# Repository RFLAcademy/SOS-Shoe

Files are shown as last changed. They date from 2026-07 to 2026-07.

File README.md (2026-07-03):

Smart Women Safety Insole - Companion App 🥿🚨

This is the official Android companion application for the Smart Women Safety Insole capstone project.

The system consists of a custom hardware insole (built with an ESP32-C3, SIM800C GPRS/GSM module, GPS, and an FSR sensor) and this Kotlin-based Android application. The app connects to a Traccar open-source backend to provide real-time location monitoring and emergency alert management.

🌟 Key Features

Live GPS Tracking: Integrates with the Google Maps SDK and Traccar API to display the real-time location of the shoe.

Route History: Automatically fetches and draws a polyline of the user's route history for the last 2 hours.

Instant SOS Alerts: If the user triggers the FSR sensor with a specific 3-taps, pause, 2-taps pattern, the app receives an immediate SOS flag and triggers a visual and auditory alarm.

Dynamic Hardware Configuration: Users can update the shoe's emergency contacts directly from the app. The app uses Android's native SmsManager to send hidden configuration commands (e.g., SET_EMERGENCY:9999999999) to the shoe, which saves the new numbers to its non-volatile flash memory.

Live Telemetry: Displays real-time speed (in knots) and UTC timestamps of the wearer's movements.

🛠️ Tech Stack

Language: Kotlin

Architecture: Android Views / XML Layouts

Maps: Google Maps API (play-services-maps)

Networking: Retrofit2 & OkHttp (for Traccar REST API communication)

Hardware Interfacing: SMS-based command transmission

🚀 How It Works

The Hardware: An ESP32 reads an FSR sensor. Upon detecting the SOS pattern, it sends an SMS to emergency contacts and pushes an &alarm=sos flag to the Traccar server via GPRS.

The Server: Traccar logs the GPS coordinates and the SOS flag.

The App: This Android app constantly polls the Traccar API using Retrofit. It updates the Google Map UI with the latest coordinates and triggers an alarm screen if the SOS flag is detected.

🔒 Setup Note

To run this project locally, you must provide your own MAPS_API_KEY in the local.properties file and set up a Traccar server instance.

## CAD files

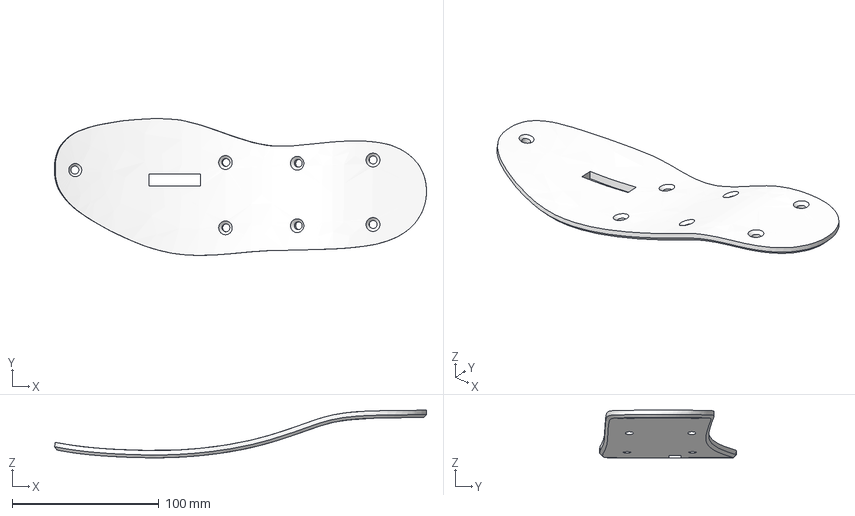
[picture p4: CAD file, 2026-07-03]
Mirrored files SOS shoes/mirrored upper shoe.step
253.7 x 93.3 x 32.5 mm

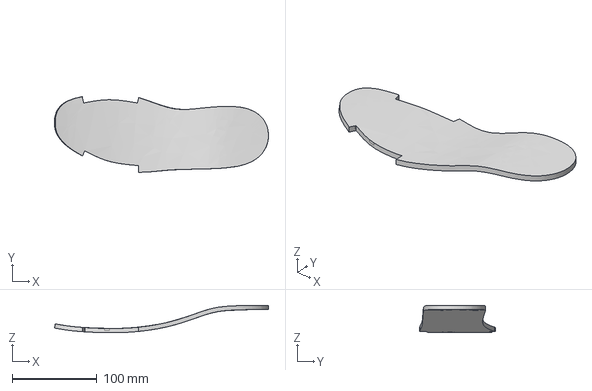
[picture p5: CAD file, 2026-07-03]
Mirrored files SOS shoes/mirrored TPU sole.step
253.1 x 89.6 x 32.5 mm

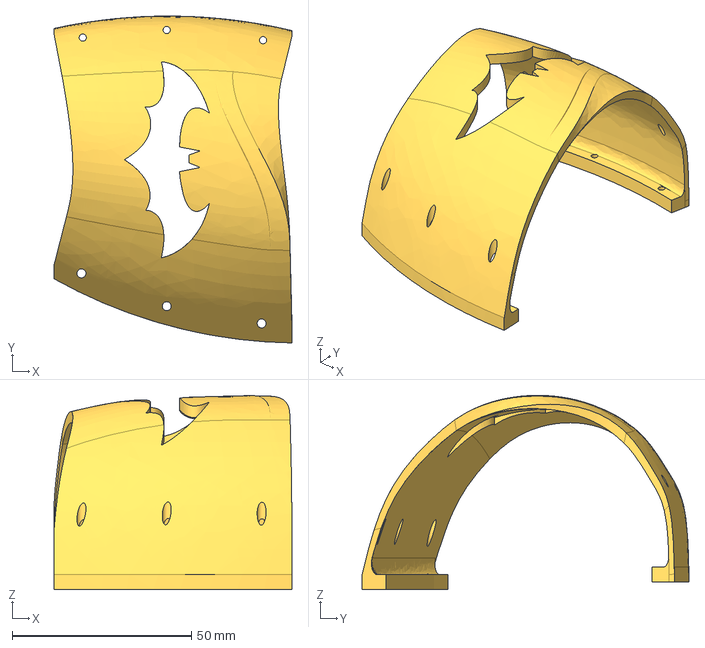
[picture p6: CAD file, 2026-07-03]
Mirrored files SOS shoes/mirrored TPU STRAP.step
66.4 x 91.2 x 54.2 mm

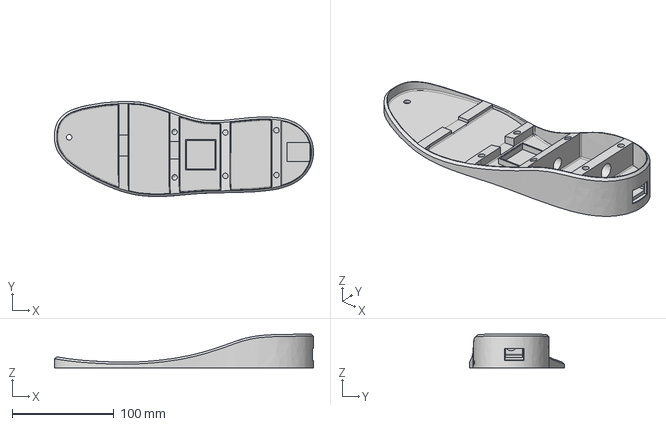
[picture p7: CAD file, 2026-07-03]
Mirrored files SOS shoes/mirrored lower shoe.step
254.2 x 93.3 x 33.3 mm

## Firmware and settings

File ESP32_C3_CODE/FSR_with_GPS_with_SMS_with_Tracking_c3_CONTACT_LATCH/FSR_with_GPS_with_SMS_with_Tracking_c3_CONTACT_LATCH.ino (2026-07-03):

#include <TinyGPS++.h>
#include <HardwareSerial.h>
#include <Preferences.h>
#include <BLEDevice.h>
#include <BLEServer.h>
#include <BLEUtils.h>
#include <BLE2902.h>

// =====================================================
//                 POWER, CHARGING & MOTOR SETUP
// =====================================================
#define RELAY_PIN 2
#define VBUS_PIN 4
#define MOTOR_PIN 5

unsigned long lastActivityTime = 0;
int lastActivityFsr = 0;
const unsigned long autoOffTimeout = 120000; // 2 minutes (120,000 ms)

// Motor Timer Variables
bool motorActive = false;
unsigned long motorStartTime = 0;
const unsigned long motorDuration = 5000; // 5 seconds

// =====================================================
//                    BLE UART SETUP
// =====================================================
BLEServer *pServer = NULL;
BLECharacteristic * pTxCharacteristic;
bool deviceConnected = false;

#define SERVICE_UUID           "6E400001-B5A3-F393-E0A9-E50E24DCCA9E"
#define CHARACTERISTIC_UUID_RX "6E400002-B5A3-F393-E0A9-E50E24DCCA9E"
#define CHARACTERISTIC_UUID_TX "6E400003-B5A3-F393-E0A9-E50E24DCCA9E"

class MyServerCallbacks: public BLEServerCallbacks {
    void onConnect(BLEServer* pServer) { deviceConnected = true; };
    void onDisconnect(BLEServer* pServer) { deviceConnected = false; }
};

// Custom Print Function - Sends to USB Serial AND Bluetooth!
void blePrintln(String msg) {
  Serial.println(msg);
  if (deviceConnected) {
    pTxCharacteristic->setValue(msg.c_str());
    pTxCharacteristic->notify();
    delay(10); // Small delay to prevent Bluetooth congestion
  }
}

// =====================================================
//                    PREFERENCES (EEPROM)
// =====================================================
Preferences preferences;

// =====================================================
//                    GPS & SIM800 SETUP
// =====================================================
TinyGPSPlus gps;
HardwareSerial gpsSerial(1);
#define GPS_RX 7
#define GPS_TX 6

HardwareSerial sim800(0);
#define SIM800_RX 20
#define SIM800_TX 21

#define MAX_CONTACTS 3
String emergencyContacts[MAX_CONTACTS] = {"9372978724", "", ""};
String apn = "airtelgprs.com";
String deviceID = "545454";

// =====================================================
//                    ADAPTIVE FSR SETUP
// =====================================================
#define FSR_PIN 3
int threshold = 2000; 

// Adaptive Tap Variables
unsigned long tapTimes[5];
unsigned long avgTapInterval = 0;
const unsigned long MAX_INITIAL_GAP = 1500;  // Max gap between regular taps
const unsigned long SEQUENCE_TIMEOUT = 3000; // Reset everything if sequence takes too long

bool tapDetected = false;
int stage = 0;
int tapCount = 0;
unsigned long lastTapTime = 0;
int filteredValue = 0;

unsigned long lastCloudUpload = 0;
const unsigned long uploadInterval = 30000;
String incomingSMS = "";

// =====================================================
//                    FUNCTIONS
// =====================================================

int readFSR() {
  int rawValue = analogRead(FSR_PIN);
  filteredValue = rawValue;
  return filteredValue;
}

void resetPattern() {
  stage = 0;
  tapCount = 0;
  avgTapInterval = 0;
  blePrintln("Pattern Reset");
}

void sendSMS(String message, String number) {
  if (number.length() < 10) return; 

  blePrintln("Sending SMS to: " + number);
  sim800.println("AT");
  delay(1000);
  sim800.println("AT+CMGF=1");
  delay(1000);
  sim800.print("AT+CMGS=\"");
  sim800.print(number);
  sim800.println("\"");
  delay(1000);
  sim800.print(message);
  delay(500);
  sim800.write(26);  
  delay(5000);
  blePrintln("SMS SENT");
}

void uploadToCloud(double lat, double lng, bool isSOS) {
  blePrintln("Uploading location to Cloud...");
  String url = "http://demo2.traccar.org:5055/?id=" + deviceID + "&lat=" + String(lat, 6) + "&lon=" + String(lng, 6);
  if (isSOS) url += "&alarm=sos";

  sim800.println("AT+SAPBR=3,1,\"Contype\",\"GPRS\"");
  delay(500);
  sim800.print("AT+SAPBR=3,1,\"APN\",\"");
  sim800.print(apn);
  sim800.println("\"");
  delay(500);
  sim800.println("AT+SAPBR=1,1");
  delay(2000);
  sim800.println("AT+HTTPINIT");
  delay(500);
  sim800.println("AT+HTTPPARA=\"CID\",1");
  delay(500);
  sim800.print("AT+HTTPPARA=\"URL\",\"");
  sim800.print(url);
  sim800.println("\"");
  delay(500);
  sim800.println("AT+HTTPACTION=0");
  delay(3000);
  sim800.println("AT+HTTPTERM");
  delay(500);
  sim800.println("AT+SAPBR=0,1");
  delay(500);
  blePrintln("Cloud Upload Complete.");
}

void handleSOS() {
  blePrintln("\n################################");
  blePrintln("######## SOS DETECTED #########");
  blePrintln("################################");

  // --- START VIBRATION MOTOR INSTANTLY ---
  digitalWrite(MOTOR_PIN, HIGH);
  motorActive = true;
  motorStartTime = millis();

  if (gps.charsProcessed() < 10) {
    blePrintln("GPS MODULE NOT DETECTED");
    for (int i = 0; i < MAX_CONTACTS; i++) {
      if (emergencyContacts[i].length() >= 10) {
          sendSMS("EMERGENCY ALERT!\nGPS module not detected.", emergencyContacts[i]);
          delay(1000);
      }
    }
    return;
  }

  if (!gps.location.isValid()) {
    blePrintln("GPS CONNECTED BUT NO LOCK");
    for (int i = 0; i < MAX_CONTACTS; i++) {
      if (emergencyContacts[i].length() >= 10) {
          sendSMS("EMERGENCY ALERT!\nGPS connected but no satellite lock.", emergencyContacts[i]);
          delay(1000);
      }
    }
    return;
  }

  double latitude = gps.location.lat();
  double longitude = gps.location.lng();
  String mapsLink = "https://maps.google.com/?q=" + String(latitude, 6) + "," + String(longitude, 6);
  blePrintln(mapsLink);

  String smsMessage = "EMERGENCY ALERT!\n\nLocation:\n" + mapsLink;
  for (int i = 0; i < MAX_CONTACTS; i++) {
    if (emergencyContacts[i].length() >= 10) {
        sendSMS(smsMessage, emergencyContacts[i]);
        delay(1000); 
    }
  }
  
  uploadToCloud(latitude, longitude, true);
}

// =====================================================
//                      SETUP
// =====================================================
void setup() {
  // --- LATCH POWER FIRST ---
  // Do this immediately so the limit switch can be released
  pinMode(RELAY_PIN, OUTPUT);
  digitalWrite(RELAY_PIN, HIGH); 
  
  // Setup Charger Detection Pin
  pinMode(VBUS_PIN, INPUT);

  // Setup Vibration Motor Pin
  pinMode(MOTOR_PIN, OUTPUT);
  digitalWrite(MOTOR_PIN, LOW); // Ensure it is off on boot

  Serial.begin(115200);
  analogReadResolution(12);

  // --- BLE SETUP ---
  BLEDevice::init("SmartShoe_BLE");
  pServer = BLEDevice::createServer();
  pServer->setCallbacks(new MyServerCallbacks());
  BLEService *pService = pServer->createService(SERVICE_UUID);
  pTxCharacteristic = pService->createCharacteristic(CHARACTERISTIC_UUID_TX, BLECharacteristic::PROPERTY_NOTIFY);
  pTxCharacteristic->addDescriptor(new BLE2902());
  pService->start();
  pServer->getAdvertising()->start();
  Serial.println("BLE Started. Waiting for connections...");

  // --- STANDARD SETUP ---
  preferences.begin("shoe_config", false);
  threshold = preferences.getInt("fsr_thresh", 2000);
  
  blePrintln("==================================");
  blePrintln(" Smart Women Safety Insole ");
  blePrintln("==================================");
  blePrintln("FSR Threshold: " + String(threshold));
  
  for (int i = 0; i < MAX_CONTACTS; i++) {
      String key = "em_contact" + String(i);
      emergencyContacts[i] = preferences.getString(key.c_str(), emergencyContacts[i]);
      if (emergencyContacts[i].length() > 0) {
          blePrintln("Loaded Emergency #" + String(i+1) + ": " + emergencyContacts[i]);
      }
  }
  
  gpsSerial.begin(9600, SERIAL_8N1, GPS_RX, GPS_TX);
  sim800.begin(9600, SERIAL_8N1, SIM800_RX, SIM800_TX);

  delay(3000);
  sim800.println("AT");
  delay(1000);
  sim800.println("AT+CMGF=1"); 
  delay(1000);
  sim800.println("AT+CNMI=1,2,0,0,0"); 
  delay(1000);

  // Initialize inactivity timer
  lastActivityTime = millis();
}

// =====================================================
//                      LOOP
// =====================================================
void loop() {
  while (gpsSerial.available() > 0) {
    gps.encode(gpsSerial.read());
  }

  while (sim800.available()) {
    char c = sim800.read();
    Serial.write(c); 
    incomingSMS += c;
    
    if (c == '\n') {
        // --- 1. SET EMERGENCY CONTACTS ---
        int cmdIndex = incomingSMS.indexOf("SET_EMERGENCY:");
        if (cmdIndex != -1) {
            String payload = incomingSMS.substring(cmdIndex + 14); 
            payload.trim();
            payload.replace(" ", ""); 
            
            for(int i = 0; i < MAX_CONTACTS; i++) emergencyContacts[i] = "";
            
            int contactIndex = 0;
            int startIndex = 0;
            int commaIndex = payload.indexOf(',');

            while (commaIndex != -1 && contactIndex < MAX_CONTACTS) {
                emergencyContacts[contactIndex] = payload.substring(startIndex, commaIndex);
                startIndex = commaIndex + 1;
                commaIndex = payload.indexOf(',', startIndex);
                contactIndex++;
            }
            if (contactIndex < MAX_CONTACTS) {
                emergencyContacts[contactIndex] = payload.substring(startIndex);
            }
            
            blePrintln("\n*** EMERGENCY NUMBERS UPDATED ***");
            for (int i = 0; i < MAX_CONTACTS; i++) {
                String key = "em_contact" + String(i);
                if (emergencyContacts[i].length() >= 10) {
                    emergencyContacts[i] = emergencyContacts[i].substring(0, 10);
                    preferences.putString(key.c_str(), emergencyContacts[i]);
                    blePrintln("Contact " + String(i+1) + ": " + emergencyContacts[i]);
                } else {
                    preferences.putString(key.c_str(), ""); 
                }
            }
        }

        // --- 2. CALIBRATE FSR COMMAND ---
        if (incomingSMS.indexOf("CALIBRATE_FSR") != -1) {
            blePrintln("\n*** STARTING CALIBRATION IN 3 SECONDS... ***");
            delay(3000); 
            
            long sum = 0;
            int samples = 50;
            for(int i=0; i<samples; i++) {
                sum += readFSR();
                delay(40); 
            }
            
            int baseline = sum / samples;
            threshold = baseline + 800; 
            
            if (threshold > 4000) threshold = 4000; 
            if (threshold < 1000) threshold = 1000; 
            
            preferences.putInt("fsr_thresh", threshold);
            blePrintln("Calibration Complete! Baseline: " + String(baseline) + " | New Threshold: " + String(threshold));
            
            if (emergencyContacts[0].length() >= 10) {
                sendSMS("Shoe Calibrated!\nNew Tap Threshold: " + String(threshold), emergencyContacts[0]);
            }
        }
        
        incomingSMS = ""; 
    }

    if (incomingSMS.length() > 200) {
        incomingSMS = "";
    }
  }

  unsigned long currentTime = millis();
  int fsrValue = readFSR();

  // --- MOTOR NON-BLOCKING TIMER LOGIC ---
  if (motorActive && (currentTime - motorStartTime >= motorDuration)) {
      digitalWrite(MOTOR_PIN, LOW);
      motorActive = false;
      blePrintln("Vibration Motor Stopped.");
  }

  // --- AUTO OFF & CHARGING LOGIC ---
  bool isCharging = digitalRead(VBUS_PIN);

  if (abs(fsrValue - lastActivityFsr) > 50) {
      lastActivityTime = currentTime;
      lastActivityFsr = fsrValue;
  }

  if (!isCharging && (currentTime - lastActivityTime > autoOffTimeout)) {
      blePrintln("Shoe inactive for 2 minutes. Turning OFF Power...");
      delay(500); 
      digitalWrite(RELAY_PIN, LOW); 
      while (true); 
  }

  // --- CLOUD TRACKING LOGIC ---
  if (currentTime - lastCloudUpload > uploadInterval) {
    if (gps.location.isValid()) {
      uploadToCloud(gps.location.lat(), gps.location.lng(), false);
    }
    lastCloudUpload = currentTime;
  }

  // --- TRAILING TAP VERIFICATION (STAGE 3) ---
  if (stage == 3) {
      // We wait for 2.5x the average tap interval. If no extra tap happens, we trigger SOS!
      if (currentTime - lastTapTime > (avgTapInterval * 2.5)) {
          blePrintln("Pattern Verified: No trailing taps detected. Triggering SOS!");
          handleSOS();
          resetPattern();
      }
  }

  // --- GENERIC SEQUENCE TIMEOUT ---
  // If the user stops tapping halfway through the pattern, reset it.
  if (tapCount > 0 && stage < 3 && (currentTime - lastTapTime > SEQUENCE_TIMEOUT)) {
      resetPattern();
  }

  // --- ADAPTIVE TAP DETECTION LOGIC ---
  if (fsrValue > threshold && !tapDetected) {
    tapDetected = true;
    lastActivityTime = currentTime; 
    
    if (stage == 0) {
      // If it's been too long since the last tap, assume this is Tap 1
      if (tapCount > 0 && (currentTime - lastTapTime > MAX_INITIAL_GAP)) {
          tapCount = 0; 
      }
      tapTimes[tapCount] = currentTime;
      tapCount++;
      blePrintln("Tap " + String(tapCount));

      if (tapCount == 3) {
         // Calculate user's natural tapping speed
         avgTapInterval = ((tapTimes[1] - tapTimes[0]) + (tapTimes[2] - tapTimes[1])) / 2;
         
         if (avgTapInterval < 100) { 
             resetPattern(); // Too fast, probably sensor noise
         } else {
             stage = 1;
             blePrintln("3 Taps. Avg Pace: " + String(avgTapInterval) + "ms. Waiting for pause...");
         }
      }
    } else if (stage == 1) {
      tapTimes[3] = currentTime;
      unsigned long pauseDuration = tapTimes[3] - tapTimes[2];

      // Pause must be at least 2x the normal tap pace, but less than 5x
      if (pauseDuration > (avgTapInterval * 1.5) && pauseDuration < (avgTapInterval * 5.0)) {
          tapCount = 4;
          stage = 2;
          blePrintln("Pause Accepted (" + String(pauseDuration) + "ms). Waiting for final tap...");
      } else {
          blePrintln("Invalid Pause: " + String(pauseDuration) + "ms. Resetting.");
          resetPattern();
          tapTimes[0] = currentTime; // Treat this invalid tap as Tap 1 of a new sequence
          tapCount = 1;
          stage = 0;
      }
    } else if (stage == 2) {
      tapTimes[4] = currentTime;
      unsigned long gapDuration = tapTimes[4] - tapTimes[3];

      // Final tap must follow the original tapping rhythm (within 2.5x avg interval)
      if (gapDuration < (avgTapInterval * 2.5)) {
          blePrintln("Final Tap Accepted! Waiting to verify no extra trailing taps...");
          stage = 3; // Enter the trailing tap verification state!
      } else {
          blePrintln("Final tap too slow. Resetting.");
          resetPattern();
          tapTimes[0] = currentTime;
          tapCount = 1;
          stage = 0;
      }
    } else if (stage == 3) {
      // If we get a tap while in Stage 3, the user is just walking. Cancel the SOS!
      blePrintln("False Alarm! Extra trailing tap detected. Cancelling SOS.");
      resetPattern();
      tapTimes[0] = currentTime;
      tapCount = 1;
      stage = 0;
    }
    lastTapTime = currentTime;
  }

  // --- RELEASE DETECTION ---
  if (fsrValue < (threshold - 200) && (millis() - lastTapTime > 80)) {
    tapDetected = false;
  }

  delay(20);
}

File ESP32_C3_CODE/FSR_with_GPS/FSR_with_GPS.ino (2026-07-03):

#include <TinyGPS++.h>
#include <HardwareSerial.h>

// ---------------- GPS ----------------
TinyGPSPlus gps;

// RX, TX for GPS
HardwareSerial gpsSerial(1);

// ---------------- FSR ----------------
#define FSR_PIN 34

// ---------------- SETTINGS ----------------
int threshold = 2000;

const unsigned long tapGapMax = 700;
const unsigned long requiredPause = 500;
const unsigned long resetTimeout = 2000;

// ---------------- VARIABLES ----------------
bool tapDetected = false;

int stage = 0;
int tapCount = 0;

unsigned long lastTapTime = 0;

// Filtering Variable
int filteredValue = 0;

// ---------------- READ FSR ----------------
int readFSR()
{
    long sum = 0;

    // Average readings
    for(int i = 0; i < 10; i++)
    {
        sum += analogRead(FSR_PIN);
        delay(2);
    }

    int rawValue = sum / 10;

    // -------- SMOOTHING FILTER --------
    filteredValue = (0.7 * filteredValue) + (0.3 * rawValue);

    return filteredValue;
}

// ---------------- RESET PATTERN ----------------
void resetPattern()
{
    stage = 0;
    tapCount = 0;

    Serial.println("Pattern Reset");
}

// ---------------- PRINT GPS ----------------
void printGPSLocation()
{
    Serial.println("");
    Serial.println("========= GPS STATUS =========");

    // -------- CASE 1 : GPS NOT CONNECTED --------
    // No GPS characters received
    if(gps.charsProcessed() < 10)
    {
        Serial.println("GPS MODULE NOT DETECTED");
        Serial.println("Check Wiring / Power");

        Serial.println("================================");
        Serial.println("");

        return;
    }

    // -------- CASE 2 : GPS CONNECTED BUT NO LOCK --------
    if(!gps.location.isValid())
    {
        Serial.println("GPS CONNECTED");
        Serial.println("WAITING FOR SATELLITE LOCK");

        Serial.print("Satellites Detected: ");

        if(gps.satellites.isValid())
        {
            Serial.println(gps.satellites.value());
        }
        else
        {
            Serial.println("Unknown");
        }

        Serial.println("Move Outdoors For Better Signal");

        Serial.println("================================");
        Serial.println("");

        return;
    }

    // -------- CASE 3 : GPS LOCK SUCCESS --------
    Serial.println("GPS LOCK SUCCESSFUL");

    Serial.print("Latitude: ");
    Serial.println(gps.location.lat(), 6);

    Serial.print("Longitude: ");
    Serial.println(gps.location.lng(), 6);

    Serial.print("Satellites: ");

    if(gps.satellites.isValid())
    {
        Serial.println(gps.satellites.value());
    }
    else
    {
        Serial.println("Unknown");
    }

    Serial.println("");

    Serial.println("Google Maps Link:");
    Serial.print("https://maps.google.com/?q=");
    Serial.print(gps.location.lat(), 6);
    Serial.print(",");
    Serial.println(gps.location.lng(), 6);

    Serial.println("================================");
    Serial.println("");
}

// ---------------- SETUP ----------------
void setup()
{
    Serial.begin(115200);

    analogReadResolution(12);

    // GPS Serial
    // RX = GPIO16
    // TX = GPIO17
    gpsSerial.begin(9600, SERIAL_8N1, 16, 17);

    Serial.println("==================================");
    Serial.println(" Smart Women Safety Insole ");
    Serial.println(" GPS + 3-2 SOS Detection ");
    Serial.println("==================================");
}

// ---------------- MAIN LOOP ----------------
void loop()
{
    // -------- READ GPS DATA --------
    while(gpsSerial.available() > 0)
    {
        gps.encode(gpsSerial.read());
    }

    int fsrValue = readFSR();

    unsigned long currentTime = millis();

    // -------- SERIAL OUTPUT --------
    // Serial.print("FSR Value: ");
    // Serial.println(fsrValue);

    // -------- TAP DETECTION --------
    if(fsrValue > threshold && !tapDetected)
    {
        tapDetected = true;

        Serial.println("TAP DETECTED");

        // Reset if too much time between taps
        if(currentTime - lastTapTime > resetTimeout)
        {
            resetPattern();
        }

        // -------- STAGE 0 --------
        if(stage == 0)
        {
            tapCount++;

            Serial.print("Stage 0 Tap Count: ");
            Serial.println(tapCount);

            if(tapCount == 3)
            {
                stage = 1;

                Serial.println("3 Taps Completed");
                Serial.println("Waiting For Pause...");
            }
        }

        // -------- STAGE 1 --------
        else if(stage == 1)
        {
            unsigned long pauseTime = currentTime - lastTapTime;

            if(pauseTime > requiredPause)
            {
                stage = 2;
                tapCount = 1;

                Serial.println("Pause Accepted");
                Serial.println("Stage 2 Started");
            }
            else
            {
                Serial.println("Pause Too Short");

                resetPattern();
            }
        }

        // -------- STAGE 2 --------
        else if(stage == 2)
        {
            if(currentTime - lastTapTime < tapGapMax)
            {
                tapCount++;

                Serial.print("Stage 2 Tap Count: ");
                Serial.println(tapCount);

                if(tapCount == 2)
                {
                    Serial.println("");
                    Serial.println("################################");
                    Serial.println("######## SOS DETECTED #########");
                    Serial.println("################################");

                    // -------- PRINT GPS --------
                    printGPSLocation();

                    delay(2000);
                    
                    resetPattern();
                }
            }
            else
            {
                Serial.println("Tap Gap Too Long");

                resetPattern();
            }
        }

        // Store latest tap time
        lastTapTime = currentTime;
    }

    // -------- RELEASE DETECTION --------
    if(fsrValue < 1200 && (millis() - lastTapTime > 80))
    {
        tapDetected = false;
    }

    delay(20);
}
